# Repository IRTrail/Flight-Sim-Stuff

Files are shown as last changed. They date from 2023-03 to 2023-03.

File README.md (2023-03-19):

# Short Final Rudder Pedals

Open Source PC flight sim rudder pedals. Intended to be robust, easily usable and customzable.

All sensing is done through hall effect sensors, so no wear.

All motion is through ball bearings or linear rails. The pedals are joined by GT2 belts, which actuate a center pulley designed to rotate 180° at full travel, thus giving maximum resolution to the pedals.

The electronics are simple, just an Arduino Pro Micro clone. I got one with a USB C port instead of USB Micro because it's more robust. I think a Teensy would do well here too, but can't find one with a USB C port. The toe brakes have a FPC (Flexible Printed Circuit) ribbon cable which works like wires with a cable chain, but is less bulky and fits in the channel of the extrusion.

## Roadmap

- Finish up GitHub page

- Actually build the first physical set...then optimize. My first part is on the printer currently.

- Add a nice assembly manual.

## FAQ

#### What printer should I use?
I print on a Voron 2.4 350 mm. I designed this to fit on a 350 mm². If you have this size printer, you should be fine. Sorry, it probably won't work on an Ender 3. The main pulley is larger than the print bed of an E3. If you absolutely can't get the parts printed, I might be convinced to print parts out for a nominal fee to cover cost and shipping, if I have time.

#### What filament should I use?
ABS or ASA. It's strong and durable. PLA is easy to print, but warps under continued stress. If you're one of those guys that prints Nylon or PEEK, you go brotha! (Also, send me a set of parts...for science!)

#### What are the print parameters?
I use the standard Voron print settings for almost everything. That amounts to:
- 4 perimeters
- 5 top and bottom shells
- ~40% infill (Gyroid or Cubic preferred)
- 0.2 mm layer height
- 0.4 mm nozzle (however, you could likely use a 0.6 mm nozzle and save some time.)

## Bill of Materials
Here will be the bill of materials when I finally have that all calculated.

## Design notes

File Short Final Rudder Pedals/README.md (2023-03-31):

# Short Final Rudder Pedals

Open Source PC flight sim rudder pedals. Intended to be robust, easily usable and customzable.

All sensing is done through hall effect sensors, so no wear.

All motion is through ball bearings or linear rails. The pedals are joined by GT2 belts, which actuate a center pulley designed to rotate 180° at full travel, thus giving maximum resolution to the pedals.

The electronics are simple, just an Arduino Pro Micro clone. I got one with a USB C port instead of USB Micro because it's more robust. I think a Teensy would do well here too, but can't find one with a USB C port. The toe brakes have a FPC (Flexible Printed Circuit) ribbon cable which works like wires with a cable chain, but is less bulky and fits in the channel of the extrusion.

## Roadmap

- Finish up GitHub page

- Currently in second stage of development. The first prototype had issues with two separate belts only joining to one pedal each. They would slip and the pedals would just move forward. Second attempt interconnects the belts such that pressure on the pedals tensions the belt and does not rely on the pulley to keep the pedals syncronized.

- Add a nice assembly manual.

## FAQ

#### What printer should I use?
I print on a Voron 2.4 350 mm. I designed this to fit on a 350 mm². If you have this size printer, you should be fine. Sorry, it probably won't work on an Ender 3. The main pulley is larger than the print bed of an E3. If you absolutely can't get the parts printed, I might be convinced to print parts out for a nominal fee to cover cost and shipping, if I have time.

#### What filament should I use?
ABS or ASA. It's strong and durable. PLA is easy to print, but warps under continued stress. If you're one of those guys that prints Nylon or PEEK, you go brotha! (Also, send me a set of parts...for science!)

#### What are the print parameters?
I use the standard Voron print settings for almost everything. That amounts to:
- 4 perimeters
- 5 top and bottom shells
- ~40% infill (Gyroid or Cubic preferred)
- 0.2 mm layer height
- 0.4 mm nozzle (however, you could likely use a 0.6 mm nozzle and save some time.)

## Bill of Materials
Here will be the bill of materials when I finally have that all calculated.

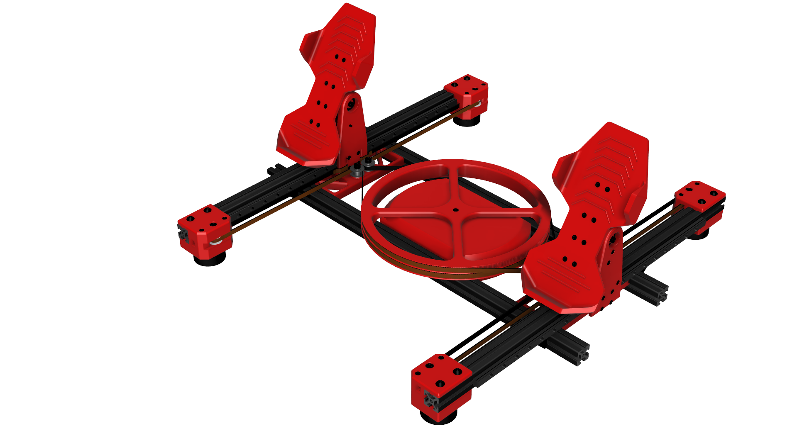
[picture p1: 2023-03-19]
Short Final Rudder Pedals/Images/Short Final Rudder Pedals.png

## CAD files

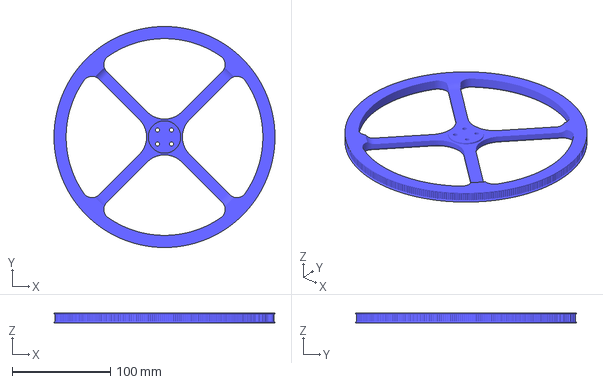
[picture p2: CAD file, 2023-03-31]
Short Final Rudder Pedals/Printable Files/Main Housing/Main Pulley.3mf
224.7 x 224.7 x 10.0 mm

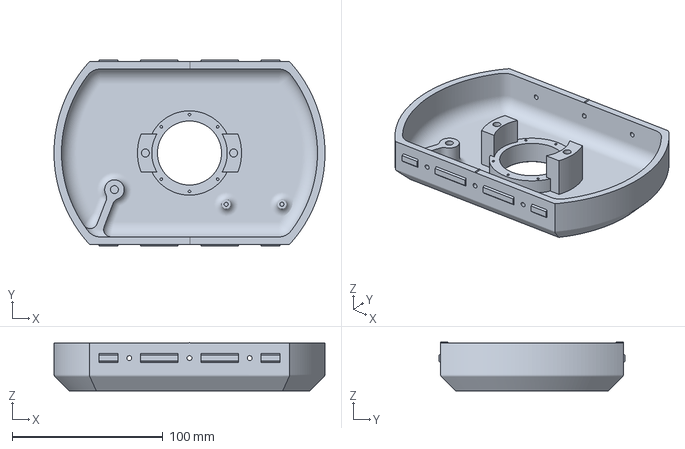
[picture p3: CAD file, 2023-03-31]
Short Final Rudder Pedals/Printable Files/Main Housing/Main Housing.3mf
180.0 x 123.4 x 32.3 mm

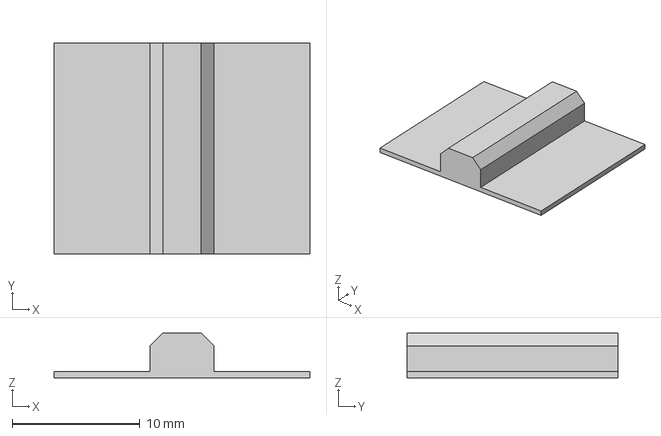
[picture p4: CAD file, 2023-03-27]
Short Final Rudder Pedals/Printable Files/Build Aids/0.5 Shim x 4.3mf
20.0 x 16.5 x 3.50 mm

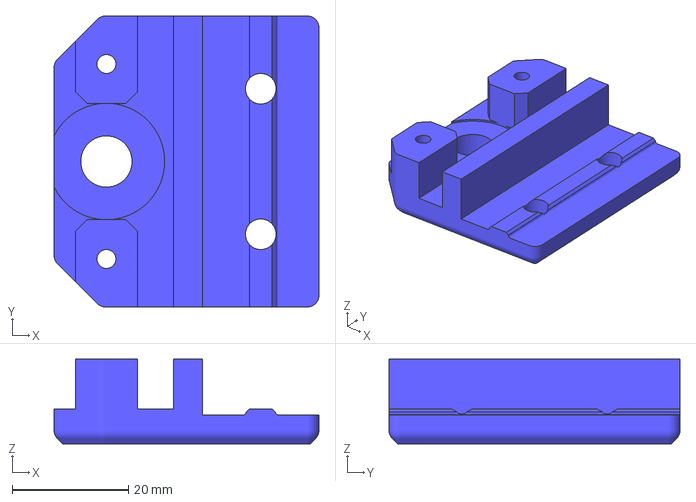
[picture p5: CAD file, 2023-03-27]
Short Final Rudder Pedals/Printable Files/End Brackets/LF Cap.3mf
45.5 x 50.0 x 14.6 mm

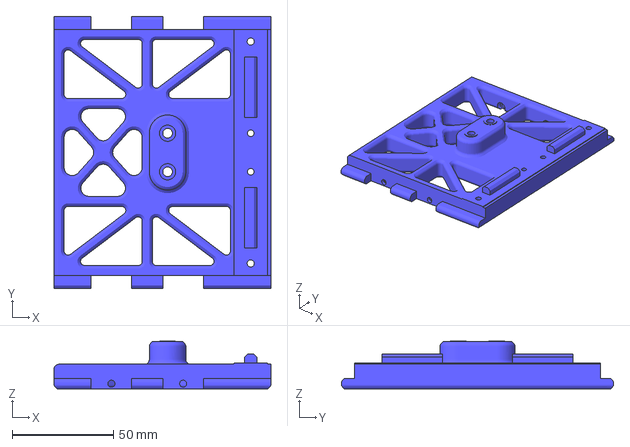
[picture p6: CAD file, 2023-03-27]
Short Final Rudder Pedals/Printable Files/Idler Brackets/Right Idler Bracket.3mf
107.0 x 134.2 x 23.6 mm

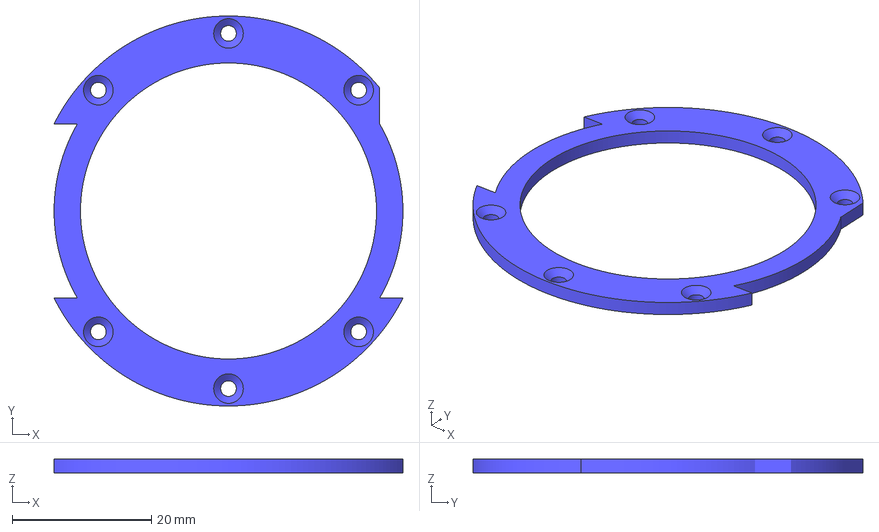
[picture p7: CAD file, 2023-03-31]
Short Final Rudder Pedals/Printable Files/Main Housing/Bearing Retainer.3mf
50.1 x 56.0 x 2.00 mm

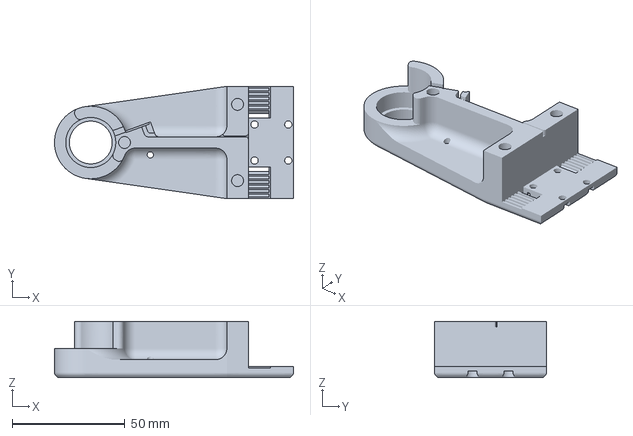
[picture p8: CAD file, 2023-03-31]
Short Final Rudder Pedals/Printable Files/Pedals/Right Inner Pedal Bracket.3mf
106.2 x 49.9 x 25.0 mm

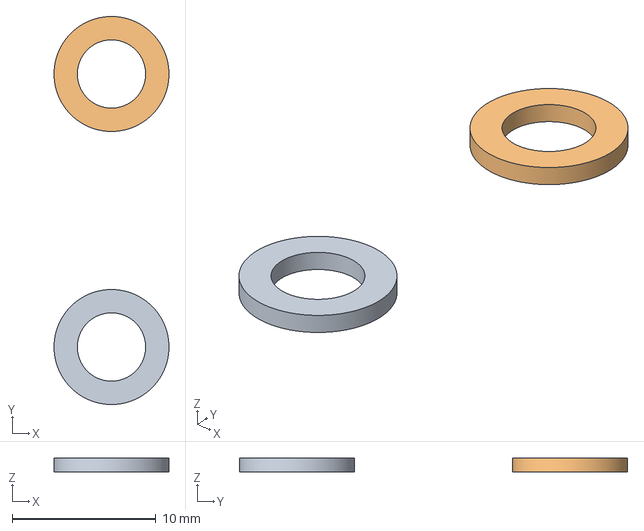
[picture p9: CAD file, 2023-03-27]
Short Final Rudder Pedals/Printable Files/Build Aids/1.0 Idler Shim.3mf
8.00 x 27.0 x 1.00 mm

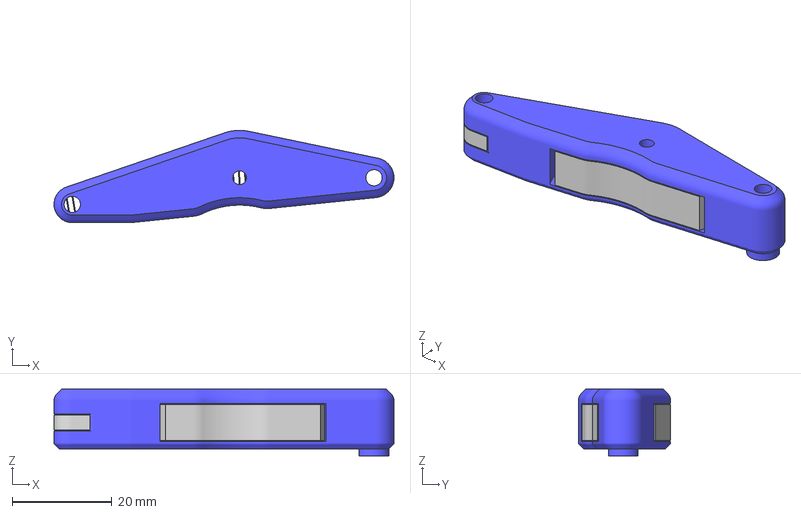
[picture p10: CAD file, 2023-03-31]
Short Final Rudder Pedals/Printable Files/Main Housing/Tensioner Arm.3mf
68.2 x 18.5 x 13.4 mm
Support (1)
Support

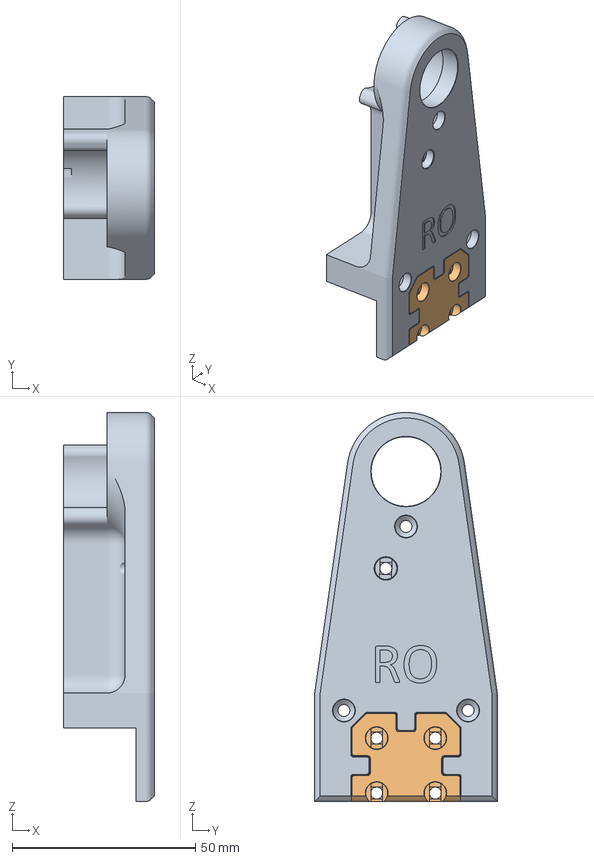
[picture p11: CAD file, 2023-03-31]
Short Final Rudder Pedals/Printable Files/Pedals/Right Outer Pedal Bracket.3mf
24.8 x 49.9 x 106.2 mm
Bracket
Plug

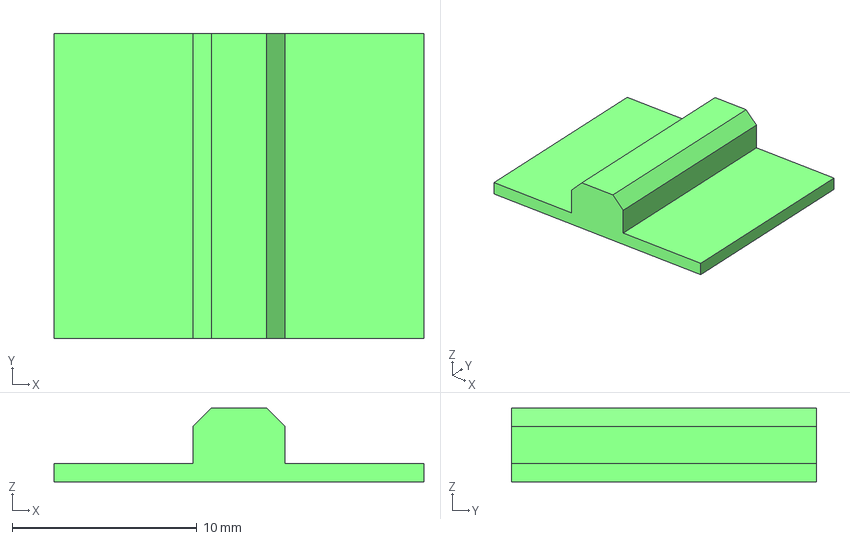
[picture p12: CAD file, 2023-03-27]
Short Final Rudder Pedals/Printable Files/Build Aids/1.0 Shim.3mf
20.0 x 16.5 x 4.00 mm

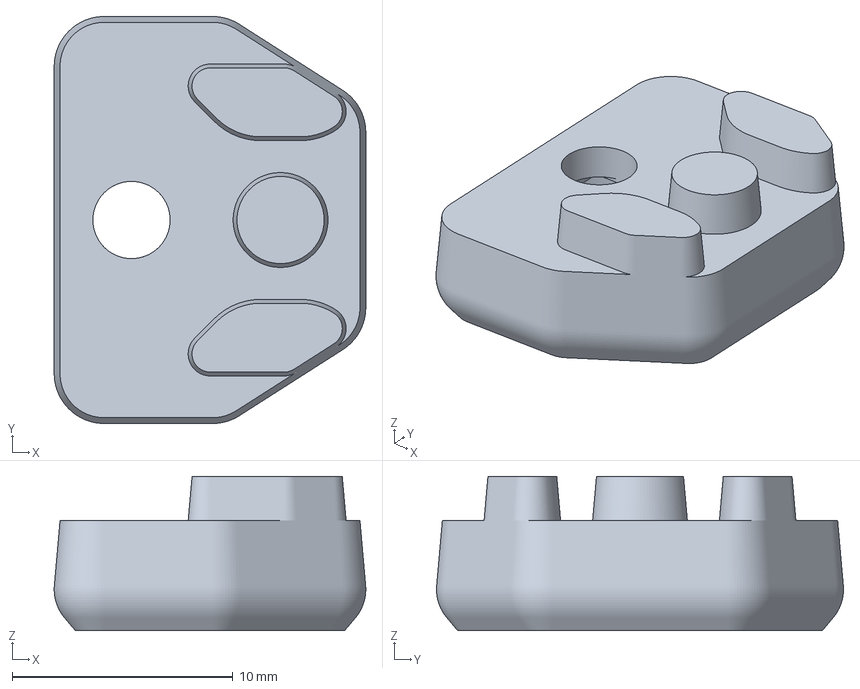
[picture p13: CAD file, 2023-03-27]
Short Final Rudder Pedals/Printable Files/End Brackets/Tension Cap x2.3mf
14.1 x 18.5 x 7.00 mm

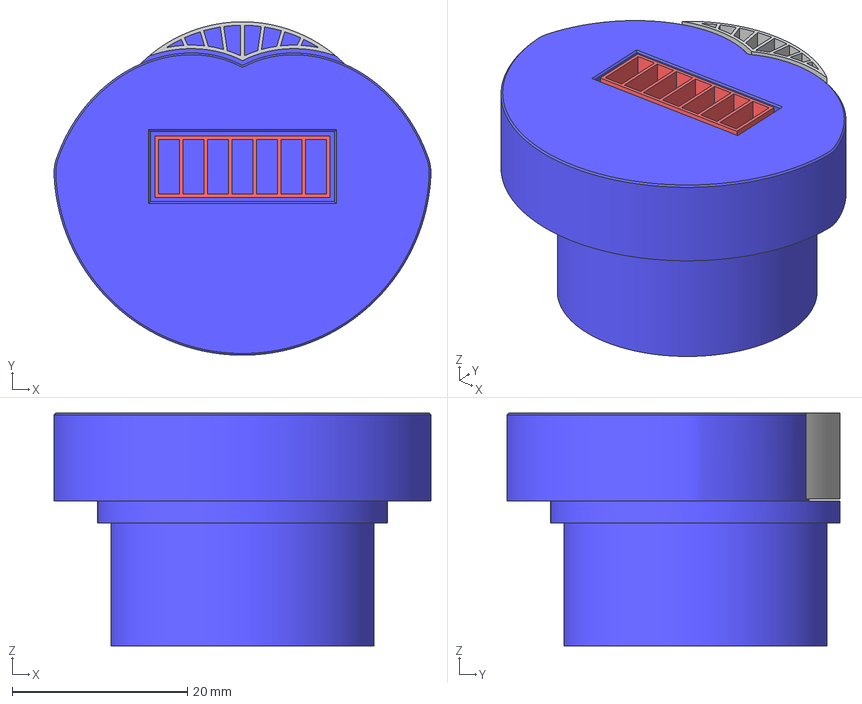
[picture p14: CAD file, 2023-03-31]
Short Final Rudder Pedals/Printable Files/Main Housing/Tension Cam.3mf
43.0 x 38.0 x 26.5 mm
Support

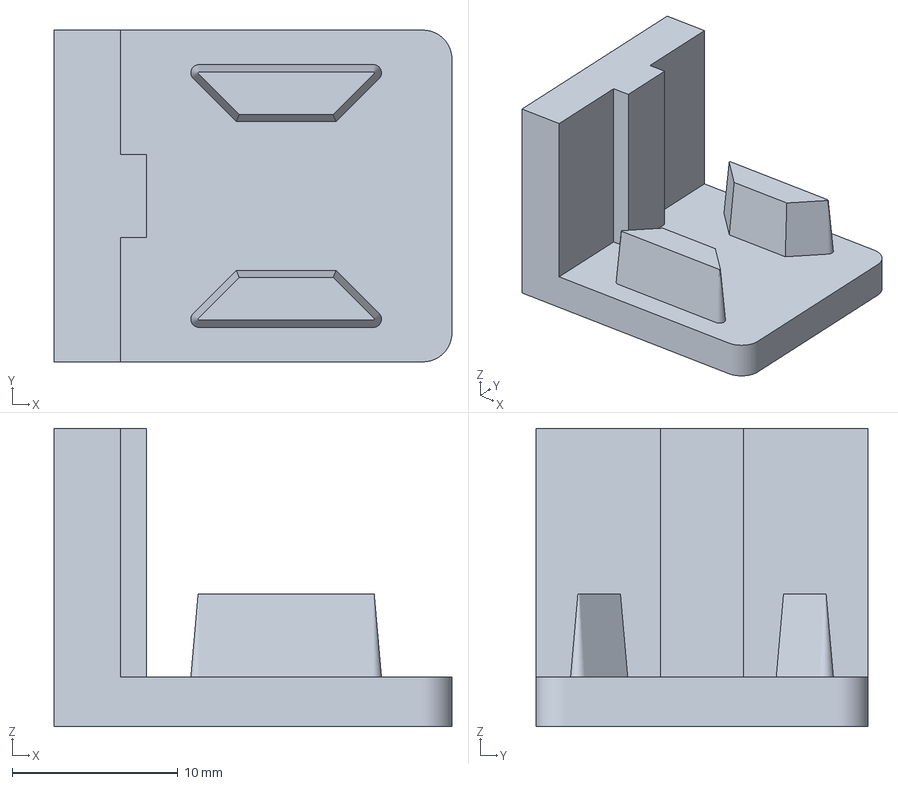
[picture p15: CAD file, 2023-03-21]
Short Final Rudder Pedals/Printable Files/Build Aids/450mm Width Spacer.3mf
24.0 x 20.0 x 18.0 mm

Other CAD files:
Short Final Rudder Pedals/Printable Files/End Brackets/RF Cap.3mf
Short Final Rudder Pedals/Printable Files/Idler Brackets/Left Idler Bracket.3mf
Short Final Rudder Pedals/Printable Files/Pedals/Left Inner Pedal Bracket.3mf
Short Final Rudder Pedals/Printable Files/End Brackets/RR Cap.3mf
Short Final Rudder Pedals/Printable Files/Build Aids/350mm Width Spacer.3mf
Short Final Rudder Pedals/Printable Files/Build Aids/400mm Width Spacer.3mf
Short Final Rudder Pedals/Printable Files/Build Aids/50mm Rail Spacer x 2.3mf
Short Final Rudder Pedals/Printable Files/End Brackets/LF Base.3mf
Short Final Rudder Pedals/Printable Files/End Brackets/LR Base.3mf
Short Final Rudder Pedals/Printable Files/End Brackets/LR Cap.3mf
Short Final Rudder Pedals/Printable Files/End Brackets/RF Base.3mf
Short Final Rudder Pedals/Printable Files/End Brackets/RR Base.3mf
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

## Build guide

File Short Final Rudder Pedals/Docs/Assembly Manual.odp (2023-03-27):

## Short Final Rudder Pedals

Assembly, Care and Feeding Manual

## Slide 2

Section 1

Frame Assembly

## Frame Side Rail Assembly

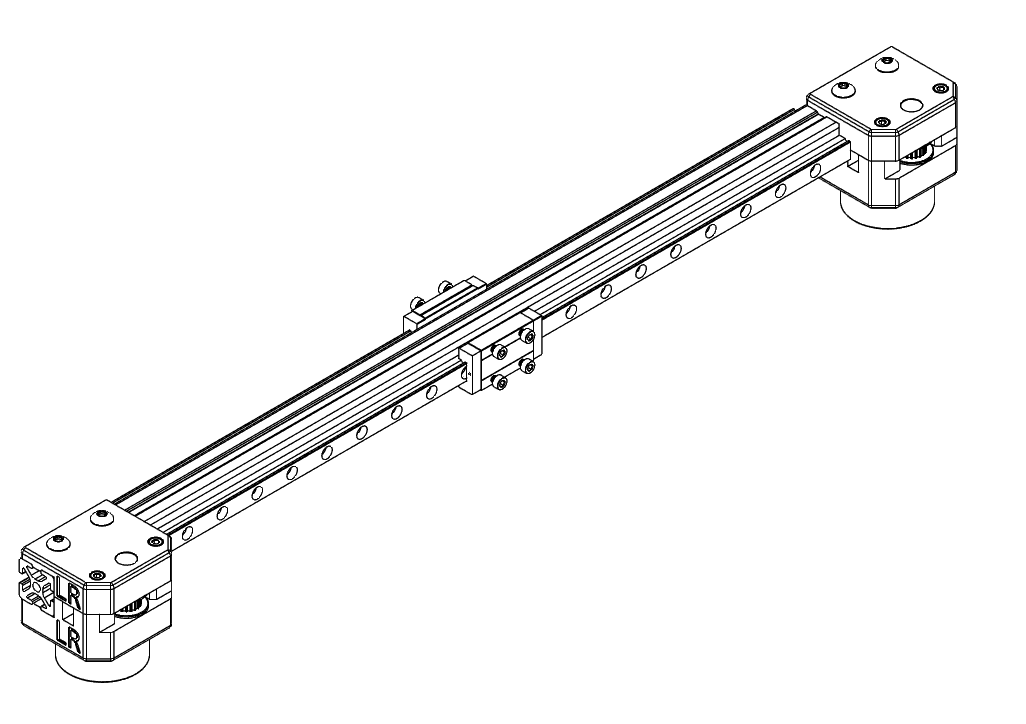
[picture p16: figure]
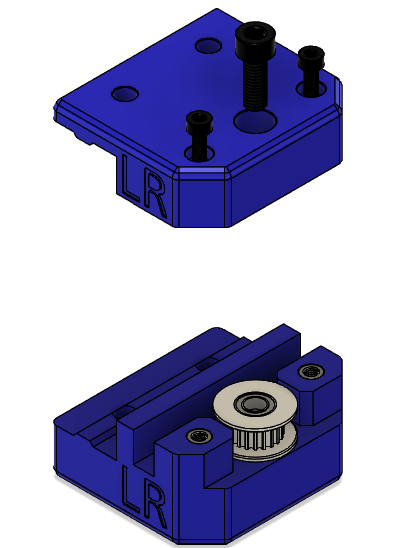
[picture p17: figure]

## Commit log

2023-03-19 Uploaded main CAD and some printable flies
    [Bearing Cap.3mf, Main Housing.3mf, Sensor Bracket.3mf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]
2023-03-19 Moved to separate folder
    [Bearing Cap.3mf, Main Housing.3mf, Sensor Bracket.3mf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]
2023-03-19 Updated parts
    [LF Base.3mf, LF Cap.3mf, LR Base.3mf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]
2023-03-20 changed part orientation to make printing easier
    [LF Base.3mf, LR Cap.3mf, Left Idler Bracket.3mf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]
2023-03-20 Last of parts uploaded. Uploaded latest CAD
    [Left Inner Pedal Bracket.3mf, Left Outer Pedal Bracket.3mf, Pedal Bushing x 4.3mf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]
2023-03-20 Adjusted part orientations
    [Left Inner Pedal Bracket.3mf, Left Outer Pedal Bracket.3mf, Pedal Bushing x 4.3mf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]
2023-03-21 Add build aids
    [350mm Width Spacer.3mf, 400mm Width Spacer.3mf, 450mm Width Spacer.3mf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]
2023-03-28 Changed pulley and tension cam interlock
    [Left Inner Pedal Bracket.3mf, Left Outer Pedal Bracket.3mf, Main Pulley.3mf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]
2023-03-31 update to larger pulley bearings
    [Bearing Cap.3mf, Bearing Retainer.3mf, Left Inner Pedal Bracket.3mf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]
